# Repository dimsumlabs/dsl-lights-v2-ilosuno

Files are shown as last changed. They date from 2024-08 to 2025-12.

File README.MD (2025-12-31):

# dsl-light v2 (ilo suno)

This repo contains the electronic design files of the new revision of DSL's RGBW LED driver board.

The original one was designed by lionello. Since I don't have Eagle, I'm redrawing the whole thing. I made the following enhancements:

* Added white LED channel
* Using ESP-WROOM-02 instead of ESP12. Both are ESP8266-based chip.
* Added bypass capacitors
* Added reverse polarity protection for voltage regulator input
* Using SMD components except for connectors
* Added mounting holes
* Replaced LDO with DC-DC buck converter
* Added power indicator
* Added programming header and removed unneeded programming button
* Added GPIO header for potential future expansion
* Replaced first-stage BJT with MOSFET
* Added gate resistor to MOSFET
* Added Dimsumlabs' logo and other info on silk mark

This new hardware design is backward-compatible with the original firmware.

## Installation Progress in DSL

2024-08-14:

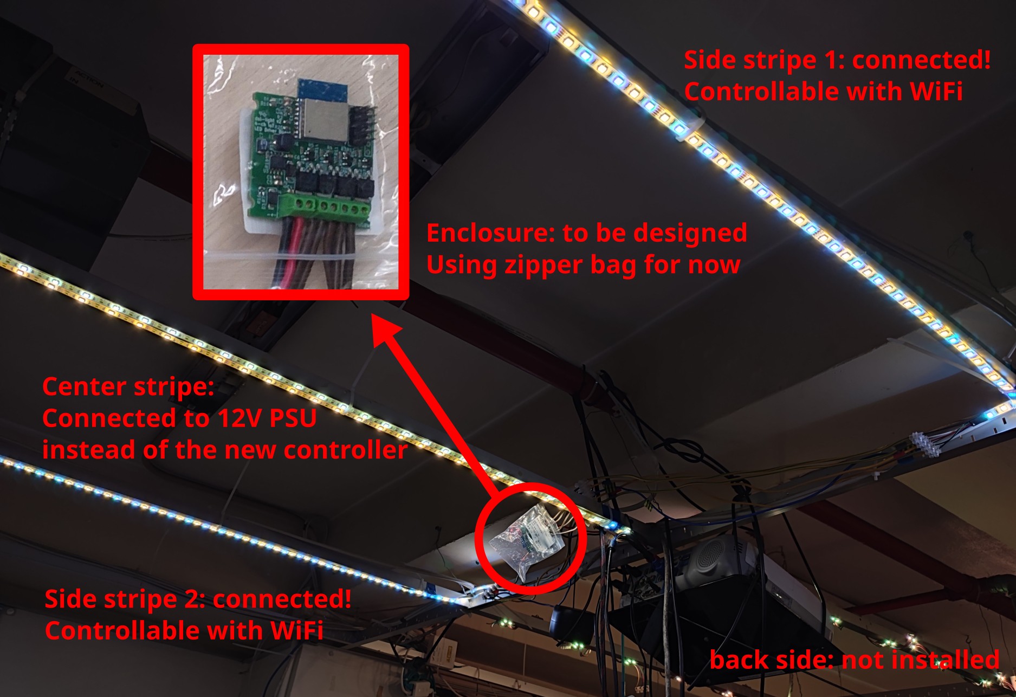
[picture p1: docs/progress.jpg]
Pic showing the Current Installation Progress in DSL as of 2024-08-14


2024-10-29:

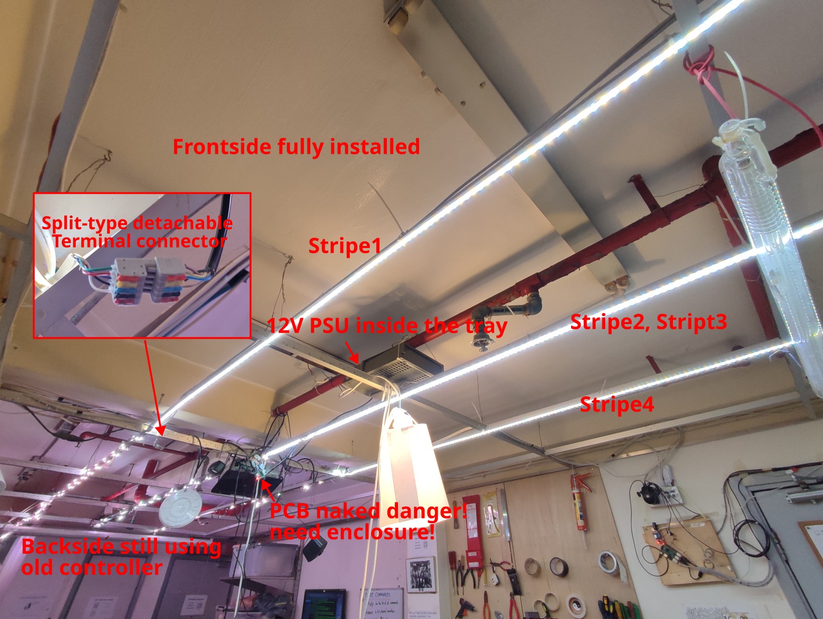
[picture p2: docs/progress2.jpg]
Pic showing the Current Installation Progress in DSL as of 2024-10-29


2025-09-13:

* Programmed the driver board with correct SSID and password so that it can be integrated with the lighting-related feature in DSL
* Obtained MAC and IP address of the driver boards so that the helios DNS can be fixed. The fix is to be performed by trouble
* Performed material recon for the installation of the backside

Thanks Nigel for wiring up the frontside driver board to the switch board. Also thanks Nigel for offering to help installing the LED strips to the backside.

2025-09-14:

* trouble had updated the DNS record. Now that the driver boards' web interface can be accessed via a domain name

2025-09-27:

* As Nigel's doing renovation, plan changed. The orignally installed strips had been rotated. Instead of using 2 LED controllers, we gotta use 5 of them. Sadale had put the 5 strips up but only one of them has controller installed for now.

2025-10-18:

* Ordered 10pcs additional units

2025-10-19:

* Drawn enclosure for the device

2025-11-01:

* Revised enclosure design with vents added
* Performed programming, flashing and testing on the 10pcs batch

2025-12-31:

* I haven't logged the progress but based on my visit in the past weeks, the installation has been completed (5 sets of LED controllers hanging on the ceiling). strerror had also vibe coded a web interface for controlling the lights!

## Credit

* lionello - For making the original design and the firmware
* Sadale - For revising the hardware design and doing the installation
* nigel - for reviewing the hardware design and doing the installation
* trouble - for proposing starting this project and reviewing the hardware design
* strerror - for doing the installation and making the web interface
* Other DSL members - for getting the whole thing installed to DSL, maintaining the firmware, etc.

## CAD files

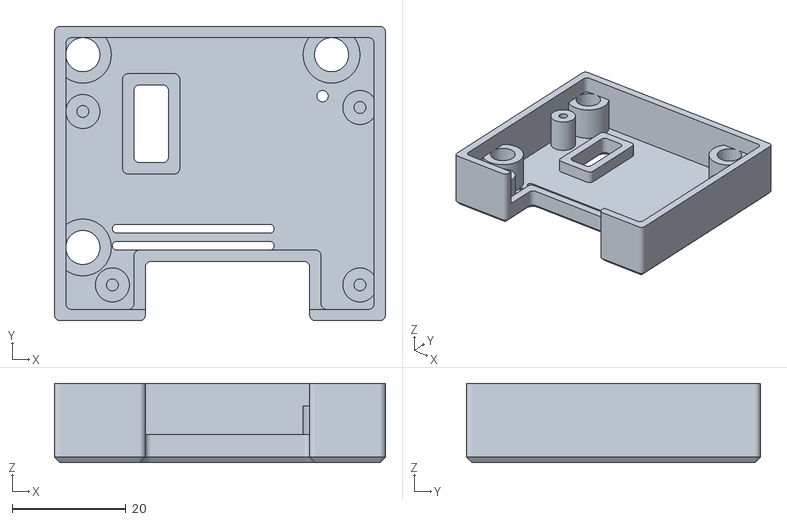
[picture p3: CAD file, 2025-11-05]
enclosure/ilosuno_enclosure-Top_Rotated.stl
58.3 x 51.8 x 14.0

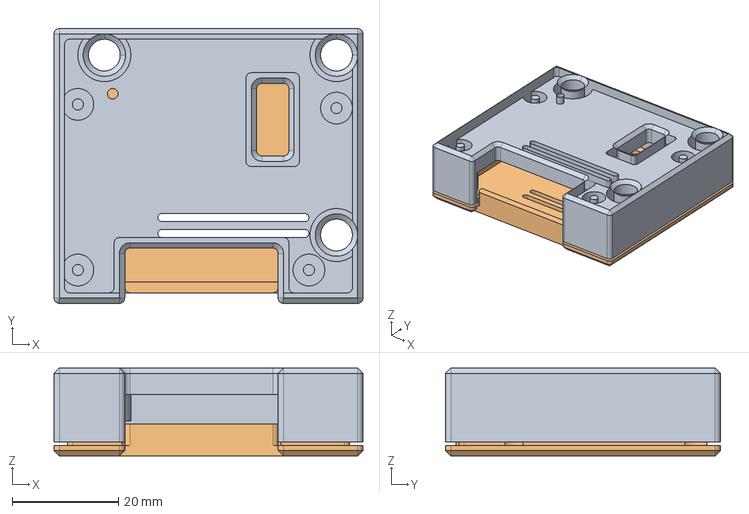
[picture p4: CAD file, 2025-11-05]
enclosure/ilosuno_enclosure.FCStd
58.3 x 51.9 x 16.6 mm
Top
Bottom

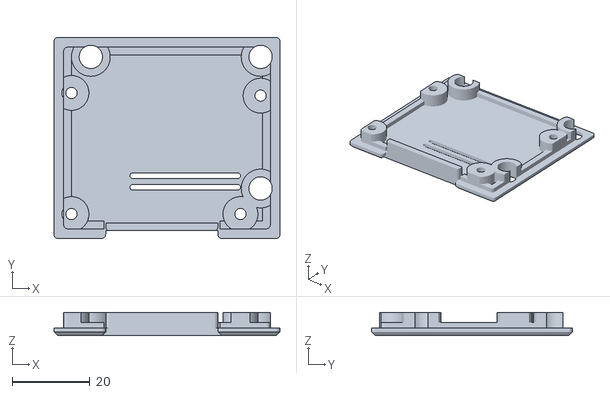
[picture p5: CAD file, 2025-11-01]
enclosure/ilosuno_enclosure-Bottom.stl
58.3 x 51.8 x 6.00

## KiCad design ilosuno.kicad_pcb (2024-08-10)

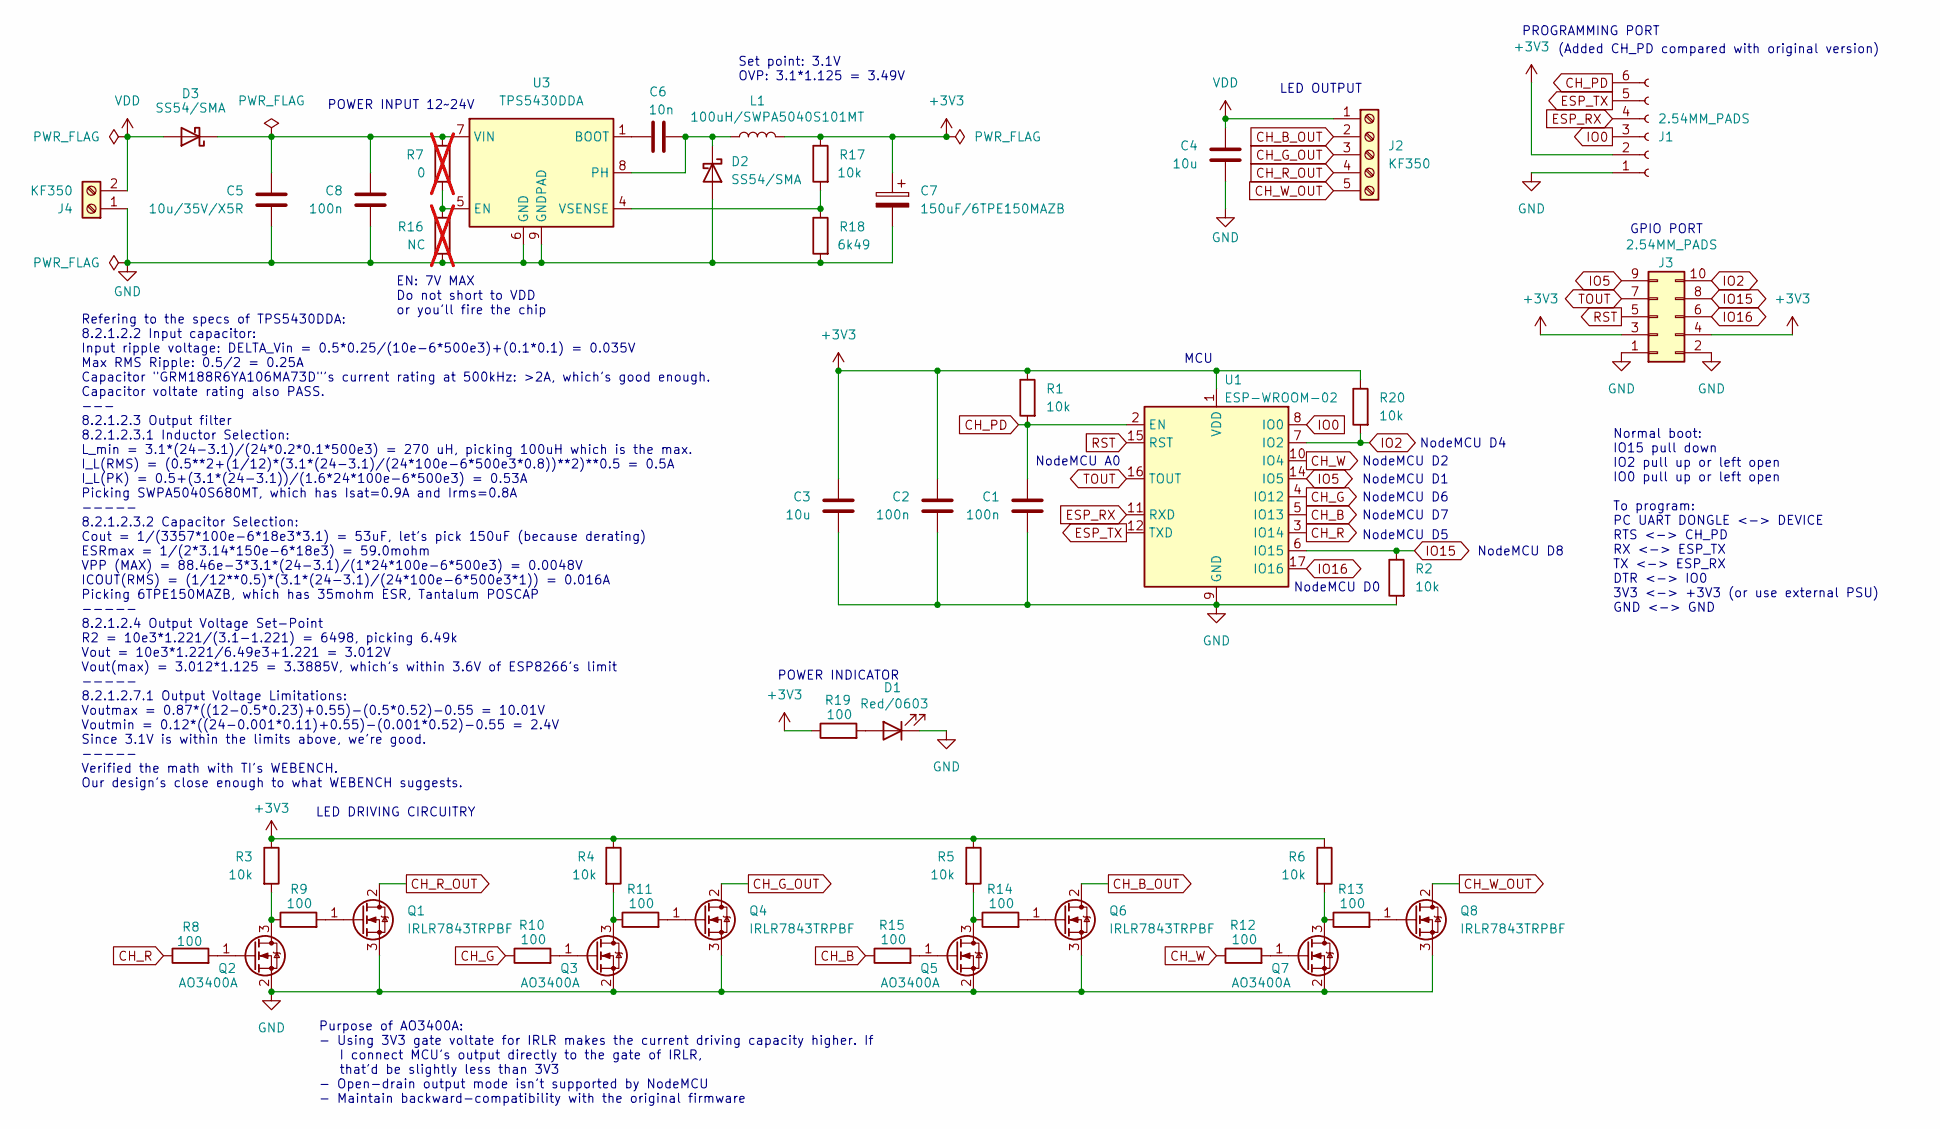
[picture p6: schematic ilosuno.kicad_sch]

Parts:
C1, C2, C8: 100n; C_0603_1608Metric; LCSC C14663
C3, C4: 10u; C_0805_2012Metric; LCSC C162422
C5: 10u/35V/X5R; C_0805_2012Metric; LCSC C162422
C6: 10n; C_0603_1608Metric; LCSC C57112
C7: 150uF/6TPE150MAZB; CP_EIA-3528-21_Kemet-B; LCSC C79110
D1: Red/0603; LED_0603_1608Metric; JLC Basic Part Y
D2, D3: SS54/SMA; D_SMA; LCSC C22452
J1: 2.54MM_PADS; PinHeader_1x06_P2.54mm_Vertical
J2: KF350; TerminalBlock_4Ucon_1x05_P3.50mm_Horizontal; LCSC both:C474893,C474892
J3: 2.54MM_PADS; PinHeader_2x05_P2.54mm_Vertical
J4: KF350; TerminalBlock_4Ucon_1x02_P3.50mm_Horizontal; LCSC C474892
L1: 100uH/SWPA5040S101MT; L_Sunlord_SWPA5040S; LCSC C88132
Q1, Q4, Q6, Q8: IRLR7843TRPBF; TO-252-2-with-heatsink; LCSC C21988
Q2, Q3, Q5, Q7: AO3400A; SOT-23; LCSC C20917
R1, R2, R3, R4, R5, R6, R17, R20: 10k; R_0603_1608Metric; LCSC C25804
R7: 0; R_0603_1608Metric; LCSC C21189; not fitted
R8, R9, R10, R11, R12, R13, R14, R15, R19: 100; R_0603_1608Metric; LCSC C22775
R16: NC; R_0603_1608Metric; not fitted
R18: 6k49; R_0603_1608Metric; LCSC C23088
U1: ESP-WROOM-02; LCSC C529584
U3: TPS5430DDA; TI_SO-PowerPAD-8_ThermalVias; LCSC C9864

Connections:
+3V3: C2.1, C3.1, C7.1, J1.2, J3.3, J3.4, L1.2, R1.1, R3.1, R4.1, R5.1, R6.1, R17.1, R19.1, R20.1, U1.1 (VDD)
CH_B: R15.1, U1.5 (IO13)
CH_B_OUT: J2.2, Q6.2 (D)
CH_G: R10.1, U1.4 (IO12)
CH_G_OUT: J2.3, Q4.2 (D)
CH_PD: C1.1, J1.6, R1.2, U1.2 (EN)
CH_R: R8.1, U1.3 (IO14)
CH_R_OUT: J2.4, Q1.2 (D)
CH_W: R12.1, U1.10 (IO4)
CH_W_OUT: J2.5, Q8.2 (D)
ESP_RX: J1.4, U1.11 (RXD)
ESP_TX: J1.5, U1.12 (TXD)
GND: C1.2, C2.2, C3.2, C4.2, C5.2, C7.2, C8.2, D1.1 (K), D2.2 (A), J1.1, J3.1, J3.2, J4.1, Q1.3 (S), Q2.2 (S), Q3.2 (S), Q4.3 (S), Q5.2 (S), Q6.3 (S), Q7.2 (S), Q8.3 (S), R2.2, R16.2, R18.2, U1.9 (GND), U1.13 (GND), U1.18 (GND), U1.19 (GND), U3.6 (GND), U3.9 (GNDPAD)
IO0: J1.3, U1.8 (IO0)
IO2: J3.10, R20.2, U1.7 (IO2)
IO5: J3.9, U1.14 (IO5)
IO15: J3.8, R2.1, U1.6 (IO15)
IO16: J3.6, U1.17 (IO16)
unnamed: D1.2 (A), R19.2
unnamed: C6.1, D2.1 (K), L1.1, U3.8 (PH)
unnamed: C5.1, C8.1, D3.1 (K), R7.1, U3.7 (VIN)
unnamed: Q1.1 (G), R9.2
unnamed: Q2.3 (D), R3.2, R9.1
unnamed: Q2.1 (G), R8.2
unnamed: Q3.3 (D), R4.2, R11.1
unnamed: Q3.1 (G), R10.2
unnamed: Q4.1 (G), R11.2
unnamed: Q5.3 (D), R5.2, R14.1
unnamed: Q5.1 (G), R15.2
unnamed: Q6.1 (G), R14.2
unnamed: Q7.3 (D), R6.2, R13.1
unnamed: Q7.1 (G), R12.2
unnamed: Q8.1 (G), R13.2
unnamed: C6.2, U3.1 (BOOT)
unnamed: R7.2, R16.1, U3.5 (EN)
unnamed: R17.2, R18.1, U3.4 (VSENSE)
RST: J3.5, U1.15 (RST)
TOUT: J3.7, U1.16 (TOUT)
VDD: C4.1, D3.2 (A), J2.1, J4.2

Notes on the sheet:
LED DRIVING CIRCUITRY
Set point: 3.1V OVP: 3.1*1.125 = 3.49V
(Added CH_PD compared with original version)
POWER INDICATOR
GPIO PORT
NodeMCU D5
LED OUTPUT
NodeMCU D4
Normal boot: IO15 pull down IO2 pull up or left open IO0 pull up or left open To program: PC UART DONGLE <-> DEVICE RTS <-> CH_PD RX <-> ESP_TX TX <-> ESP_RX DTR <-> IO0 3V3 <-> +3V3 (or use external PSU) GND <-> GND
NodeMCU D7
NodeMCU D2
MCU
PROGRAMMING PORT
NodeMCU D6
Purpose of AO3400A: - Using 3V3 gate voltate for IRLR makes the current driving capacity higher. If I connect MCU's output directly to the gate of IRLR, that'd be slightly less than 3V3 - Open-drain output mode isn't supported by NodeMCU - Maintain backward-compatibility with the original firmware
Refering to the specs of TPS5430DDA: 8.2.1.2.2 Input capacitor: Input ripple voltage: DELTA_Vin = 0.5*0.25/(10e-6*500e3)+(0.1*0.1) = 0.035V Max RMS Ripple: 0.5/2 = 0.25A Capacitor "GRM188R6YA106MA73D"'s current rating at 500kHz: >2A, which's good enough. Capacitor voltate rating also PASS. --- 8.2.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
EN: 7V MAX Do not short to VDD or you'll fire the chip
NodeMCU D0
POWER INPUT 12~24V
NodeMCU D1
NodeMCU D8
NodeMCU A0

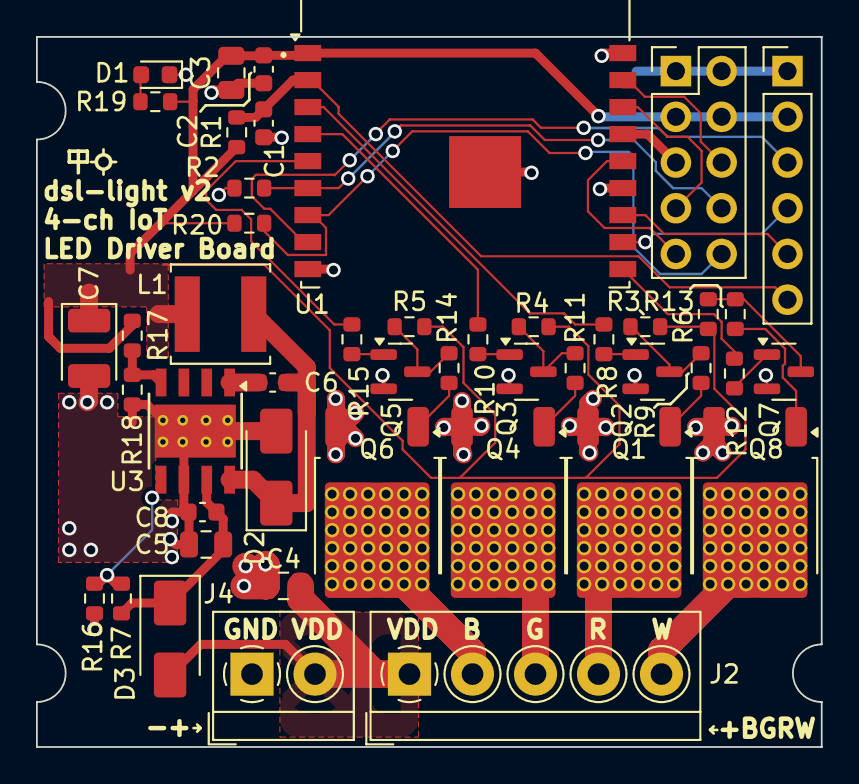
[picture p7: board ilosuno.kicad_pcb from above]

Board: 2 copper layers, 43.6 x 39.5 mm, 46 parts (0 on the bottom side), 39 nets.

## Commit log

2024-07-27 Initial commit - revision 0g
    [ilosuno.kicad_pcb, ilosuno.kicad_sch]
2024-07-28 rev1a: Fixed buck converter output overvoltage bug. Added reverse polarity protection. Exposed more pins to GPIO header (RST, IO2 and IO15)
    [ilosuno.kicad_pcb, ilosuno.kicad_sch]
2024-08-03 rev1b: Corrected silk mark in regard to the required initial boot pin state, with on-board pull-down considered
    [ilosuno.kicad_pcb]
2024-08-03 Documented the math for buck converter with the new capacitor value, inductor value and the new voltage set point
    [ilosuno.kicad_sch]
2024-08-10 Bug fixed: Buck converter EN pin overvoltage
    [ilosuno.kicad_pcb, ilosuno.kicad_sch]
2025-10-19 Added first revision of enclosure
    [ilosuno_enclosure-Bottom.stl, ilosuno_enclosure-Top_Rotated.stl, ilosuno_enclosure.FCStd]
2025-10-19 Added LED indicator hole on the enclosure
    [ilosuno_enclosure-Top_Rotated.stl, ilosuno_enclosure.FCStd]
2025-11-01 enclosure: Added vents; Enlarged clearance hole to 2.9mm
    [ilosuno_enclosure-Bottom.stl, ilosuno_enclosure-Top_Rotated.stl, ilosuno_enclosure.FCStd]
2025-11-02 enclosure: Increased LED indicator hole size from 1mm to 2mm
    [ilosuno_enclosure-Top_Rotated.stl, ilosuno_enclosure.FCStd]
2025-11-05 enclosure: Enlarged the tapping hole size from 2mm to 2.1mm to account for 3D printing shrinkage
    [ilosuno_enclosure-Top_Rotated.stl, ilosuno_enclosure.FCStd]
